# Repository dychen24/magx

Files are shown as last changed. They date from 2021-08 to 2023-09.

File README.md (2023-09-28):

# About

This directory contains codes and PCB files for MagX, as described in :

>  [_MagX: Wearable, Untethered Hands Tracking with Passive Magnets_]
>  Dongyao Chen, Mingke Wang, Chenxi He, Qing Luo,
>  Yasha Iravantchi, Alanson Sample, Kang G. Shin and Xinbing Wang.
>  In Proceedings of the ACM MobiCom 2021.

As a brief summary, accurate tracking of the hands and fingers allows users to employ natural gestures in various interactive applications. Hand tracking also supports health applications, such as monitoring face-touching, a common vector for infectious disease. However, for both types of applications, the utility of hand tracking is often limited by the impracticality of bulky tethered systems (e.g., instrumented gloves) or inherent limitations (e.g., Line of Sight or privacy concerns with vision-based systems).

We present MagX, a fully untethered on-body hand tracking system utilizing passive magnets and a novel magnetic sensing platform.  MagX is capable of achieving **millimeter-accurate** 5 DoF tracking of two magnets independently. For example, at 11 cm distance, a 6cm*6cm sensing array can achieve positional and orientational errors of 0.76 cm and 0.11 rad. At 21 cm distance, the tracking errors are 2.65 cm and 0.41 rad. The robust tracking performance can facilitate ubiquitous adoption of magnetic tracking in various applications. Furthermore, MagX can perform all compute locally and only requires ~0.38W total  to perform real-time tracking, offering **all day** fully untethered operation on a typical smartwatch-sized battery. 

plot

# License

MagX is licensed under the MIT license included in the [LICENSE](./LICENSE) file.

# Setup

To use MagX, you'll need the following tools and hardwares:
  * [MagX sensing array](#magx-sensing-array-manufacturing)
  * [Arduino IDE](#arduino-ide-setup)
  * [Anaconda](#python-environment-setup)
  * Homebrew for macOS

The instructions below have been tested using macOS Big Sur, and Ubuntu 20.04. 

## MagX sensing array manufacturing
To learn more about the manufacturing of the MagX sensing array, please see the related [README](./pcb/README.md) file in `/pcb`.

## Arduino IDE setup
1. Download and install [Arduino IDE](https://www.arduino.cc/en/software)
2. Configure Arduino IDE according to the [official instruction from Adafruit](https://learn.adafruit.com/bluefruit-nrf52-feather-learning-guide/arduino-bsp-setup)
3. install the Adafruit MLX90393 Library for Arduino using the Library Manager in the Arduino IDE:
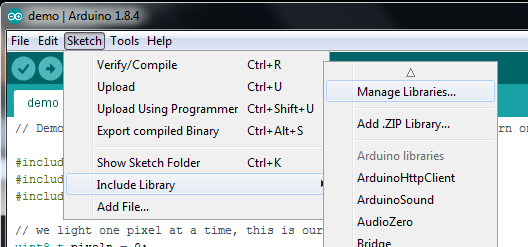
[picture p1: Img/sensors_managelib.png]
    

    Click the Manage Libraries ... menu item, search for Adafruit MLX90393, and select the Adafruit MLX90393 library:
    plot
4. (Optional) Replace `Adafruit_MLX90393.cpp` and `Adafruit_MLX90393.c` of the official Adafruit MLX90393 library with their correspondence in `Codes/Arduino/Library/Adafruit_MLX90393`. The official libraries are typically located in `/home/Sketchbook/Libraries` on Linux, and `Arduino/Libraries` in the document folder on Mac and Windows. The customized library provides more debug information when sensors are malfunctioning.

## Python environment setup
1. Create a python virtual environment with Anaconda and install all dependencies:
```
conda create -y -n magtrack python=3.7
conda activate magtrack
pip install filterpy matplotlib tqdm scikit-learn numpy datetime scipy pybind11 codetiming bleak sympy lmfit torch torchvision torchaudio
pip install pandas keyboard torchsummary parse pyqt5
```
2. Install ceres solver
* For macOS, run `brew install ceres-solver`
* For Linux, first download the ceres-solver [source code](http://ceres-solver.org/installation.html). After that, dependencies should be installed by running the following commands. 
    ```
    # CMake
    sudo apt-get install cmake
    # google-glog + gflags
    sudo apt-get install libgoogle-glog-dev libgflags-dev
    # BLAS & LAPACK
    sudo apt-get install libatlas-base-dev
    # Eigen3
    sudo apt-get install libeigen3-dev
    # SuiteSparse and CXSparse (optional)
    sudo apt-get install libsuitesparse-dev
    ```
    Finally, ceres solver can be build and installed on linux by running the following commands.
    ```
    tar zxf ceres-solver-2.0.0.tar.gz
    mkdir ceres-bin
    cd ceres-bin
    cmake ../ceres-solver-2.0.0
    make -j3
    make install
    ```
3. Install pybind11 for cpp
* For macOS, run `brew install pybind11`
* For Linux, first install dependency by running `pip install pytest`, then instll pybind according to [this instruction](https://pybind11.readthedocs.io/en/stable/basics.html).
4. Install customized cpp solver
    ```
    cd Codes/cpp_solver 
    pip install ./

# Run a quick demo
1. Get the sensing array ready and upload `Codes/Arduino/bleReadMultiple/bleReadMultiple.ino` to the sensing array
2. Run `Codes/read_raw_ble/find_device.py` to find the address of the Adafruit chip you are using. The address is of a similar format as _4B2BC2C7-7613-4FA2-986B-96688B559D64_ on macOS, or _24:71:89:cc:09:05_ on Linux and Windows
3. Before running `Codes/read_raw_ble/read_sensor.py`, replace the BLE address on line 66 with the address found in step 2. Also, change the output file name on line 31.
4. Run `Codes/read_raw_ble/read_sensor.py` to collect calibration data for the sensors. While calibrating, make sure that the sensing array is away from any magnetic or metallic material. Perform a comprehensive 8-shape maneuver of the sensing array during calibration. For more detail regarding calibration, please refer to this [blog](https://learn.adafruit.com/adafruit-sensorlab-magnetometer-calibration). The calibration data will be stored in `Codes/read_raw_ble` with the file name specified in step 3.
5. Before running `Codes/optimization/real_time_pos.py`, replace the BLE address on line 53 with the address found in step 2. Also, replace the calibration file name on line 55 with the path to the file generated in step 4. 
7. Run `Codes/optimization/real_time_pos.py`. 
    * By default, the code tracks 1 magnet. To track 2 magnets, change line 318 to `asyncio.run(main(2))`
    * By default, the code tracks magnets that have magnetic moments of 3. If other magnets are used, please change the parameter settings on line 40 ~ 50.
    * By default, the code assumes that the 9.8cm\*9.8cm (aka the "large") sensor array is used. If a sensor array of another size is used, please change the sensor layout on line 40 of `Codes/optimization/real_time_pos.py`. The code ships with 3 sensor layouts, the 9.8cm\*9.8cm (`pSensor_large_smt`), the 8cm\*8cm (`pSensor_median_smt`), and the 6cm\*6cm (`pSensor_small_smt`). 

# Code Layout

See the [Codes](./Codes/codes.md) file for more details on the various files in the repository.

# Version History
- v0.1:  Initial code release

# Citing MagX
If you use MagX in your research or wish to refer to the baseline results, please use the following BibTeX entry.

```BibTeX
@inproceedings{MagX2021,
  author    = {Chen, Dongyao and Wang, Mingke and He, Chenxi and Luo, Qing and Iravantchi, Yasha and Sample, Alanson and Shin, Kang G. and Wang, Xinbing},
  title     = {MagX: Wearable, Untethered Hands Tracking with Passive Magnets},
  year      = {2021},
  isbn      = {9781450383424},
  publisher = {Association for Computing Machinery},
  address   = {New York, NY, USA},
  url       = {https://doi.org/10.1145/3447993.3483260},
  doi       = {10.1145/3447993.3483260},
  booktitle = {Proceedings of the 27th Annual International Conference on Mobile Computing and Networking},
  pages     = {269–282},
  numpages  = {14},
  keywords  = {untethered, hand tracking, magnetic sensing},
  location  = {New Orleans, Louisiana},
  series    = {MobiCom '21}
}
```

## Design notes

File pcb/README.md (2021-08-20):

# PCB Design

## Folder Description
"6cmX6cm_layout" is a 6cm X 6cm sensing array, and "9.8cmX9.8cm_layout" is a 9.8cm X 9.8cm sensing array. Both of them are composed of two printed circuit board, top board and bottom board.

"bom" refers to bill of materials, i.e., the components needed to build a sensing array.

## PCB Design Tool and Library
We utilize Altium Designer (version 20.0.13) to design PCB boards. The component library of capacitive and resistance adopts the standard library. The footprint of magnetic field sensor, MLX90393, can see https://www.snapeda.com/parts/MLX90393SLW-ABA-011-RE/Melexis%20Technologies/view-part/551380/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.

## Assembly
We use 9 separate pin headers to join the two boards together. A common 3-pin linear regulator is used to stabilize the output voltage, which is set to 3.3v. A 16-pin female header and a 12-pin female header are welded to the bottom board to connect the Bluefruit nRF52 Feather.

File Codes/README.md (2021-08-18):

# All codes for MagX

## Arduino
1. batteryTest: read battery voltage and level of an Adafruit Feather
2. bleReadMultiple: read readings from 8 magnetometers and send them via bluetooth
3. localReadMultiple: read readings from 8 magnetometers and print them in serial port
4. Library: modified library for Adafruit_MLX90393

## leapmotion
Code for gathering groundtruth using a Leap Motion Controller. The ground truth is stored in a csv file. Leap Motion 2.7 python SDK must be first installed

## read_raw_ble
Read measurements from an Adafruit Feather sent by bluetooth. Before reading the measurement using read_sensor.py, use find_device.py to find the address of the device, and change the address in read_sensor.py accordingly

## cpp_solver
C++ wrapped solver of the LM algorithm.

## optimization
All codes for finding the optimal layout and tracking magnets. For more detail please refer to the readme file inside the folder.

## requirements.txt
All python libraries used

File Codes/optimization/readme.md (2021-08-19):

# The layout of the folder
- Visulization.py: used to track the magnet, visulize the result, and compare the result to the ground truth offline. The ground truth and the data should be stored as CSV (likely gathered by codes in `../leapmotion` and `../read_raw_ble`).
- real_time_pos.py: used to show the tracking result in real-time.
    - real_time_pos_belly.py: used for endocapsule tracking demo.
    - real_time_pos_car.py: used for driver hand monitoring demo.
    - real_time_pos_face.py: used for face touching demo.
    - real_time_pos_hand.py: used for hand tracking demo.
- simulation.py: generate simulated data and use it to validate the performance of the sensor layout.
- find_best_Loc.py: use PSO to find the best layout of the sensor array given the physical constraint.

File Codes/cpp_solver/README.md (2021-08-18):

# Readme
This folder stores the cpp implementation of the LM algorithm. 
The source file locates in  *./src*

This library consist three functions:
- solve_1mag
- solve_2mag
- CalB

## Usage
### solve_1mag
- input:
  - readings: the sensor readings at time $t$
  - pSensor: the location of each sensor
  - init_param: the initialization parameters. It's a array of size 9. The meaning of each parameter goes in the following order: 
  $G_x, G_y , G_z, log(m), x, y, z, \theta, \phi$.**Noted that logrithm should be applied to magnet moment $m$**

- output:
  - result: It's a array of size 9, just like _init_param_ . This set of parameter fit the sensor reading the best.

### solve_2mag
- input:
  - readings: the sensor readings at time $t$
  - pSensor: the location of each sensor
  - init_param: the initialization parameters. It's a array of size 9. The meaning of each parameter goes in the following order: 
  $G_x, G_y , G_z, log(m), x_0, y_0, z_0, \theta_0, \phi_0, x_1, y_1, z_1, \theta_1, \phi_1$

- output:
  - result: It's a array of size 9, just like _init_param_ . This set of parameter fit the sensor reading the best. **Noted that in the function both magnet has the same magnet moment $m$**.

### CalB
- input:
  - pSensor: the location of each sensor
  - init_param: the initialization parameters. It's a array of size 9. The meaning of each parameter goes in the following order: 
  $G_x, G_y , G_z, m, x, y, z, \theta, \phi$

- output:
  - result: The result is the simulated sensor reading given the magnet position and the sensor position.

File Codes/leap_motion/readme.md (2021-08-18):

# Leap Motion Setup Procedure

1. Download and install [Leap Motion SDK](https://developer.leapmotion.com/sdk-leap-motion-controller). We used Version 2.3.1 on macOS.
2. Put `LeapPython.so`, `libLeap.dylib` and `Leap.py` in `LeapSDK/lib` into this folder.
3. Plug the leap motion controller into your computer and run the Leap Motion Diagnostic Visualizer to check if the device is working properly.
4. Turn on the tool tracking mode and turn off the hand tracking mode of Leap Motion. On macOS, the settings are under `Tracking` of `Leap Motion Control Panel`.
5. Run `ground_truth.py` with Python 2.7. Change the output file name at the beginning of the file in advance. 
6. For more information regarding Leap Motion, please visit [this website](https://developer.leapmotion.com/desktop-leap-motion-controller/). During the first run of the code, you might encounter error `Fatal Python error: PyThreadState_Get: no current thread`. Please refer to this [page](https://stackoverflow.com/questions/42401156/leap-motion-error-fatal-python-error-pythreadstate-get-no-current-thread-abor) for a fix

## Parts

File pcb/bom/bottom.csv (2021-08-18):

Comment | Description | Designator | Footprint | LibRef | Pins | Quantity
0.1uF | capacitance | C7_2,C7,C11_2,C11,C15_2,C15,C16_2,C16 | CAP_0603 | CAP | 2 | 8
10k | resistance | R1,R2 | RES_0603 | RES | 2 | 2
MLX90393 | sensor | MS7,MS11,MS15,MS16 | MLX90393 | MLX90393SLW ABA 011 RE | 17 | 4

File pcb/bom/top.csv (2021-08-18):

Comment | Description | Designator | Footprint | LibRef | Pins | Quantity
0.1uF | capacitance | C30_2,CSD,CSD_2,CSC,CSC_2,C30,C27,C27_2 | CAP_0603 | CAP | 2 | 8
MLX90393 | sensor | MSSD,MSSC,MS30,MS27 | MLX90393 | MLX90393SLW ABA 011 RE | 17 | 4

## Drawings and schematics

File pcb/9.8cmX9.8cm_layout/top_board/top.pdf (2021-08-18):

SC27

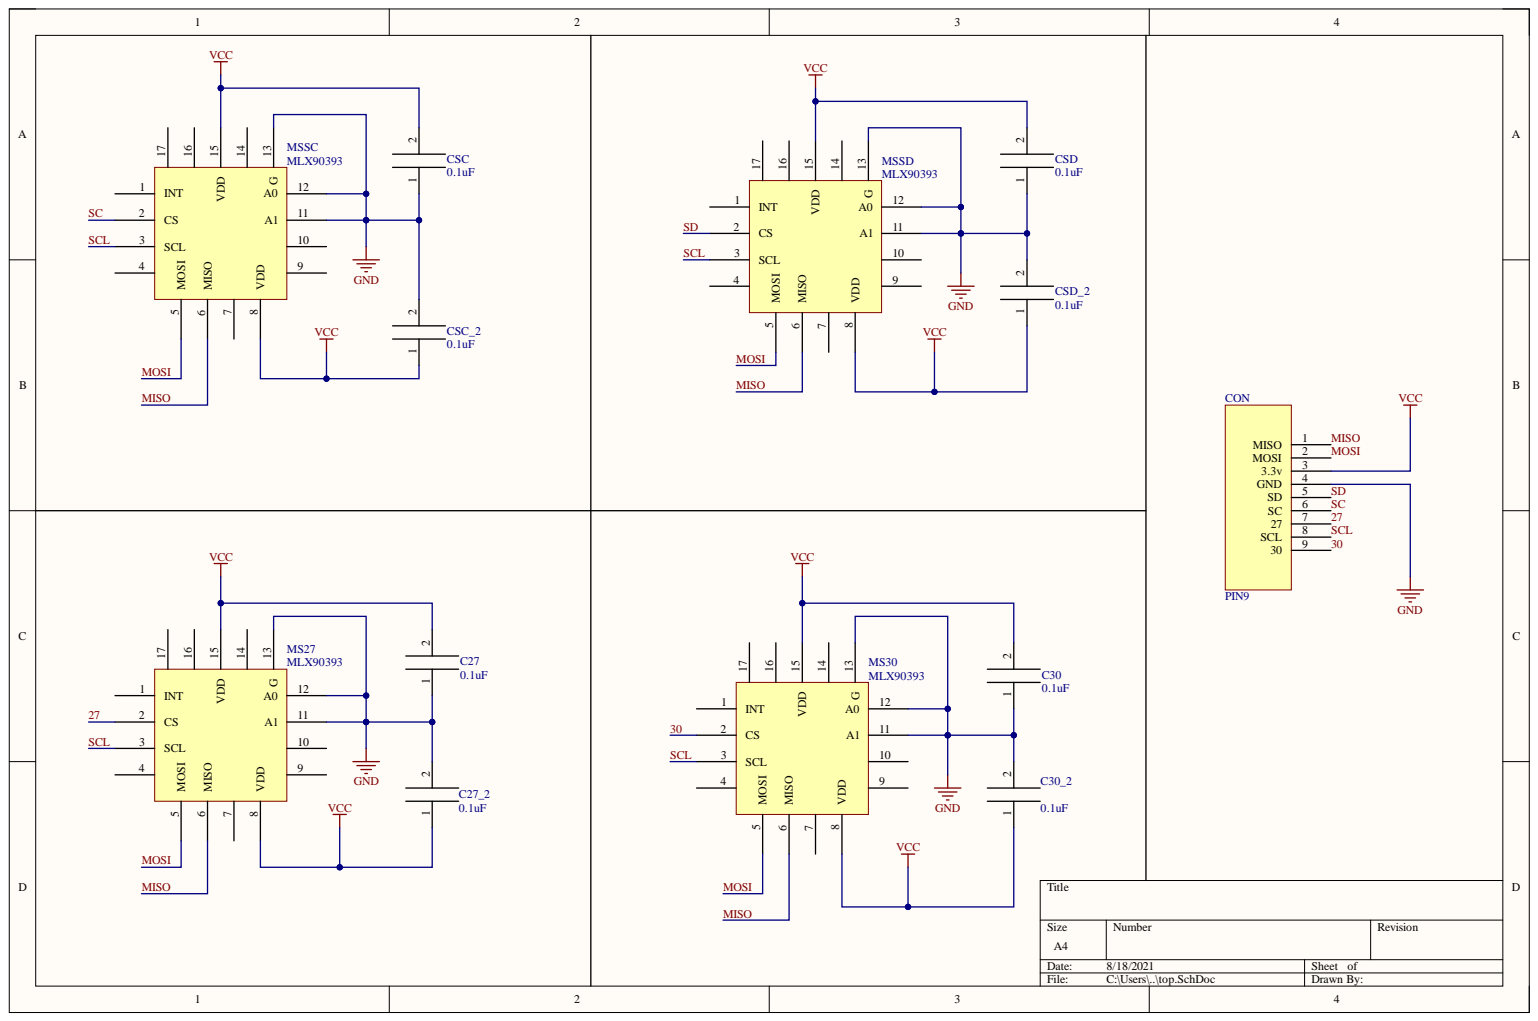
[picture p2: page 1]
Size; mber; Rev; Date:; Sheet o; sers; p.Sch; Draw; CSC 0.1uF; CSD 0.1uF; CSC_; CSD; MISO; MOSI; SCL; VCC; VCC GND; MOSI 5; MISO 6; VDD 8; VDD 15; MSSC ML; MSSD ML

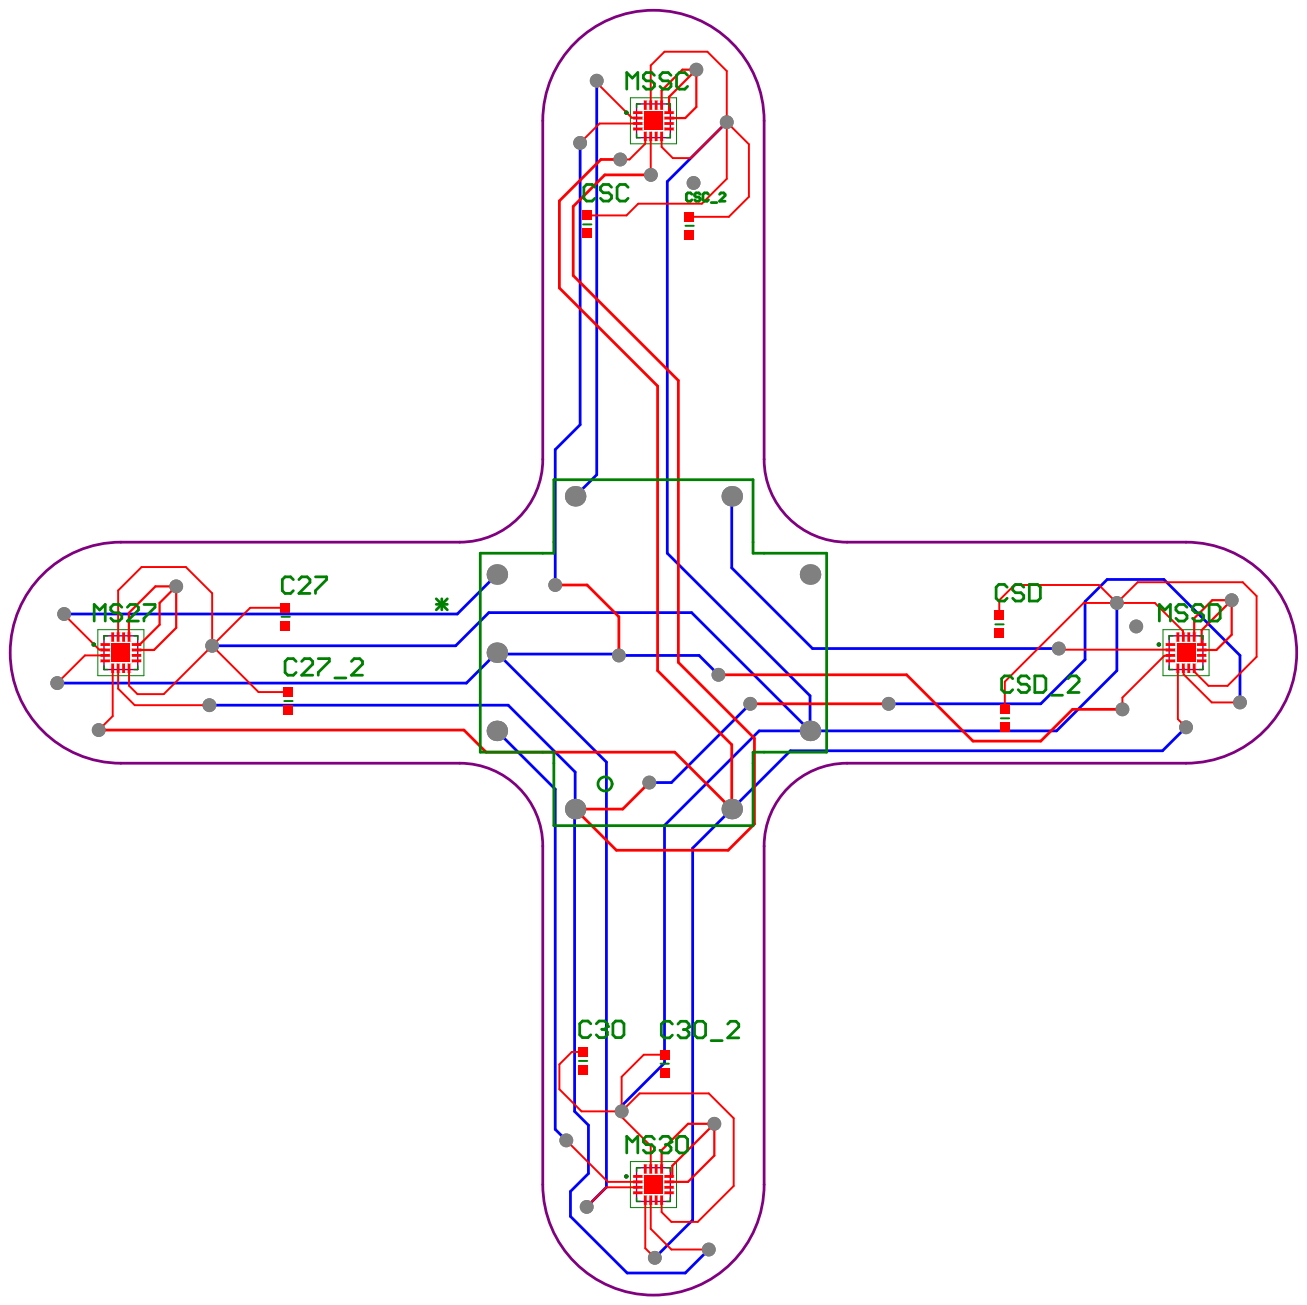
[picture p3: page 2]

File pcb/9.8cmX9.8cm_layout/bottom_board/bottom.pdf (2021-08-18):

4 | SCK 23 | A5 22 | A4 21 | A3 20 | A2 19 | A1 18 | A0 17 | GND 16 | 3.3v 15 | 3.3v 14 | RESE
2 SCL | 11 27 | 10 30 | 9 31 | 8 11 | 7 7 | 6 15 | 5 16 | 4 USB | 3 EN | 2

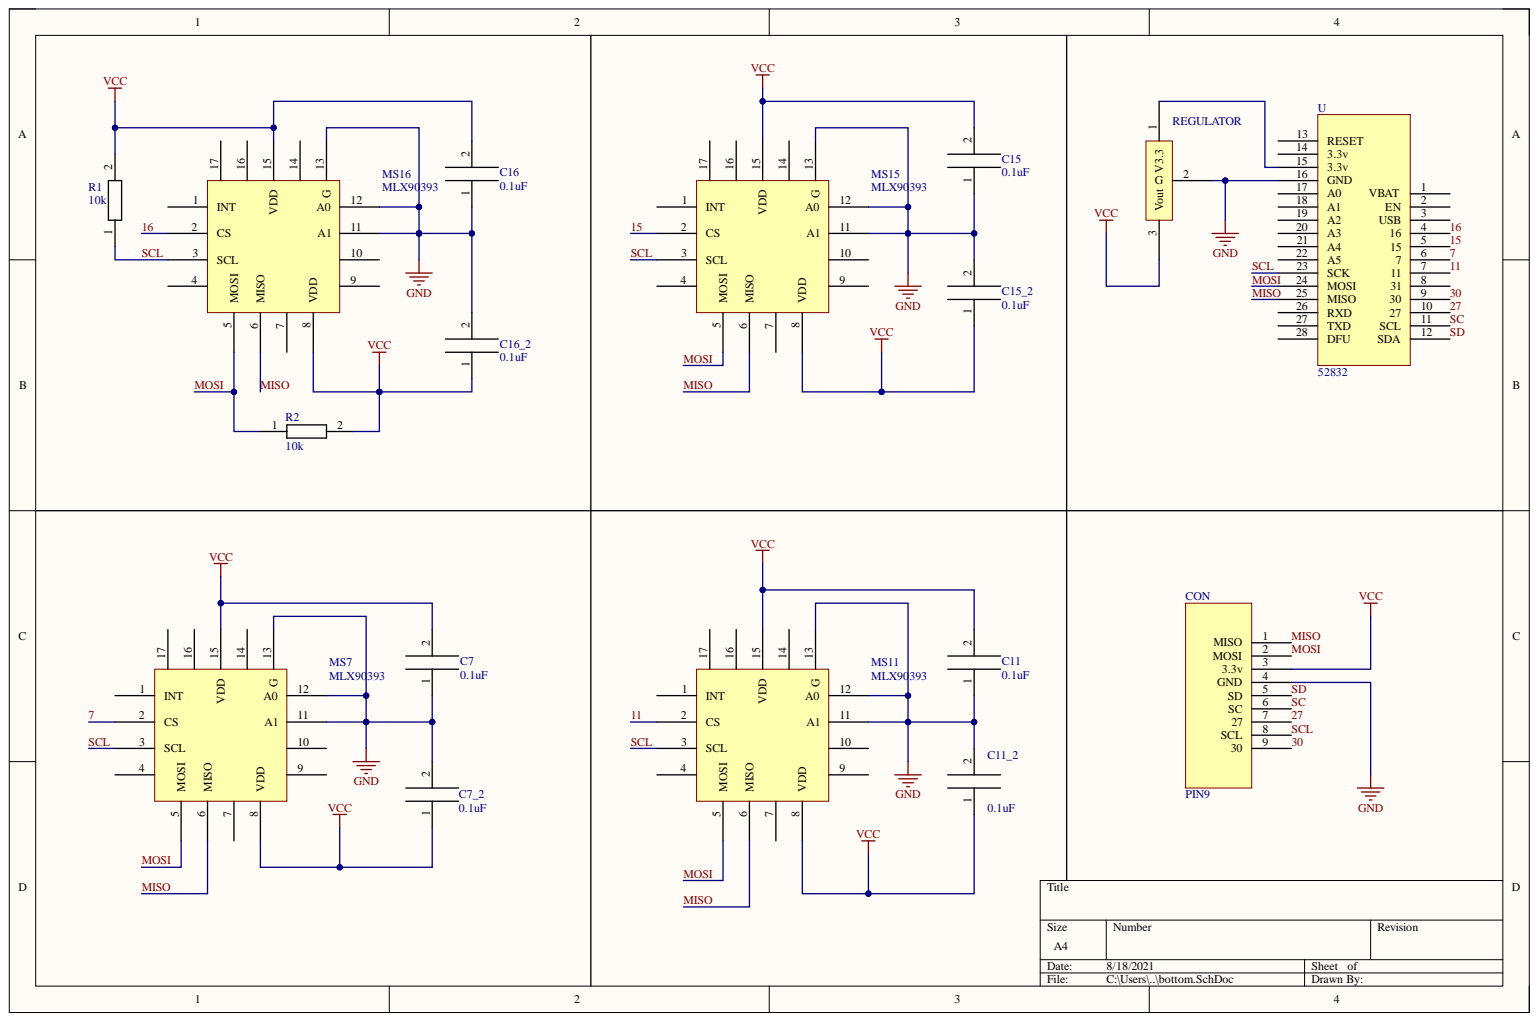
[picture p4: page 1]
Size; mber; Rev; Date:; Sheet o; sers; m.Sch; Draw; V3.3 1 Vout 3 G; DFU; MISO; MOSI; VBAT; SCL; VCC; R1 10kVCC; VCC GND; MOSI 5; MISO 6; VDD 8; VDD 15

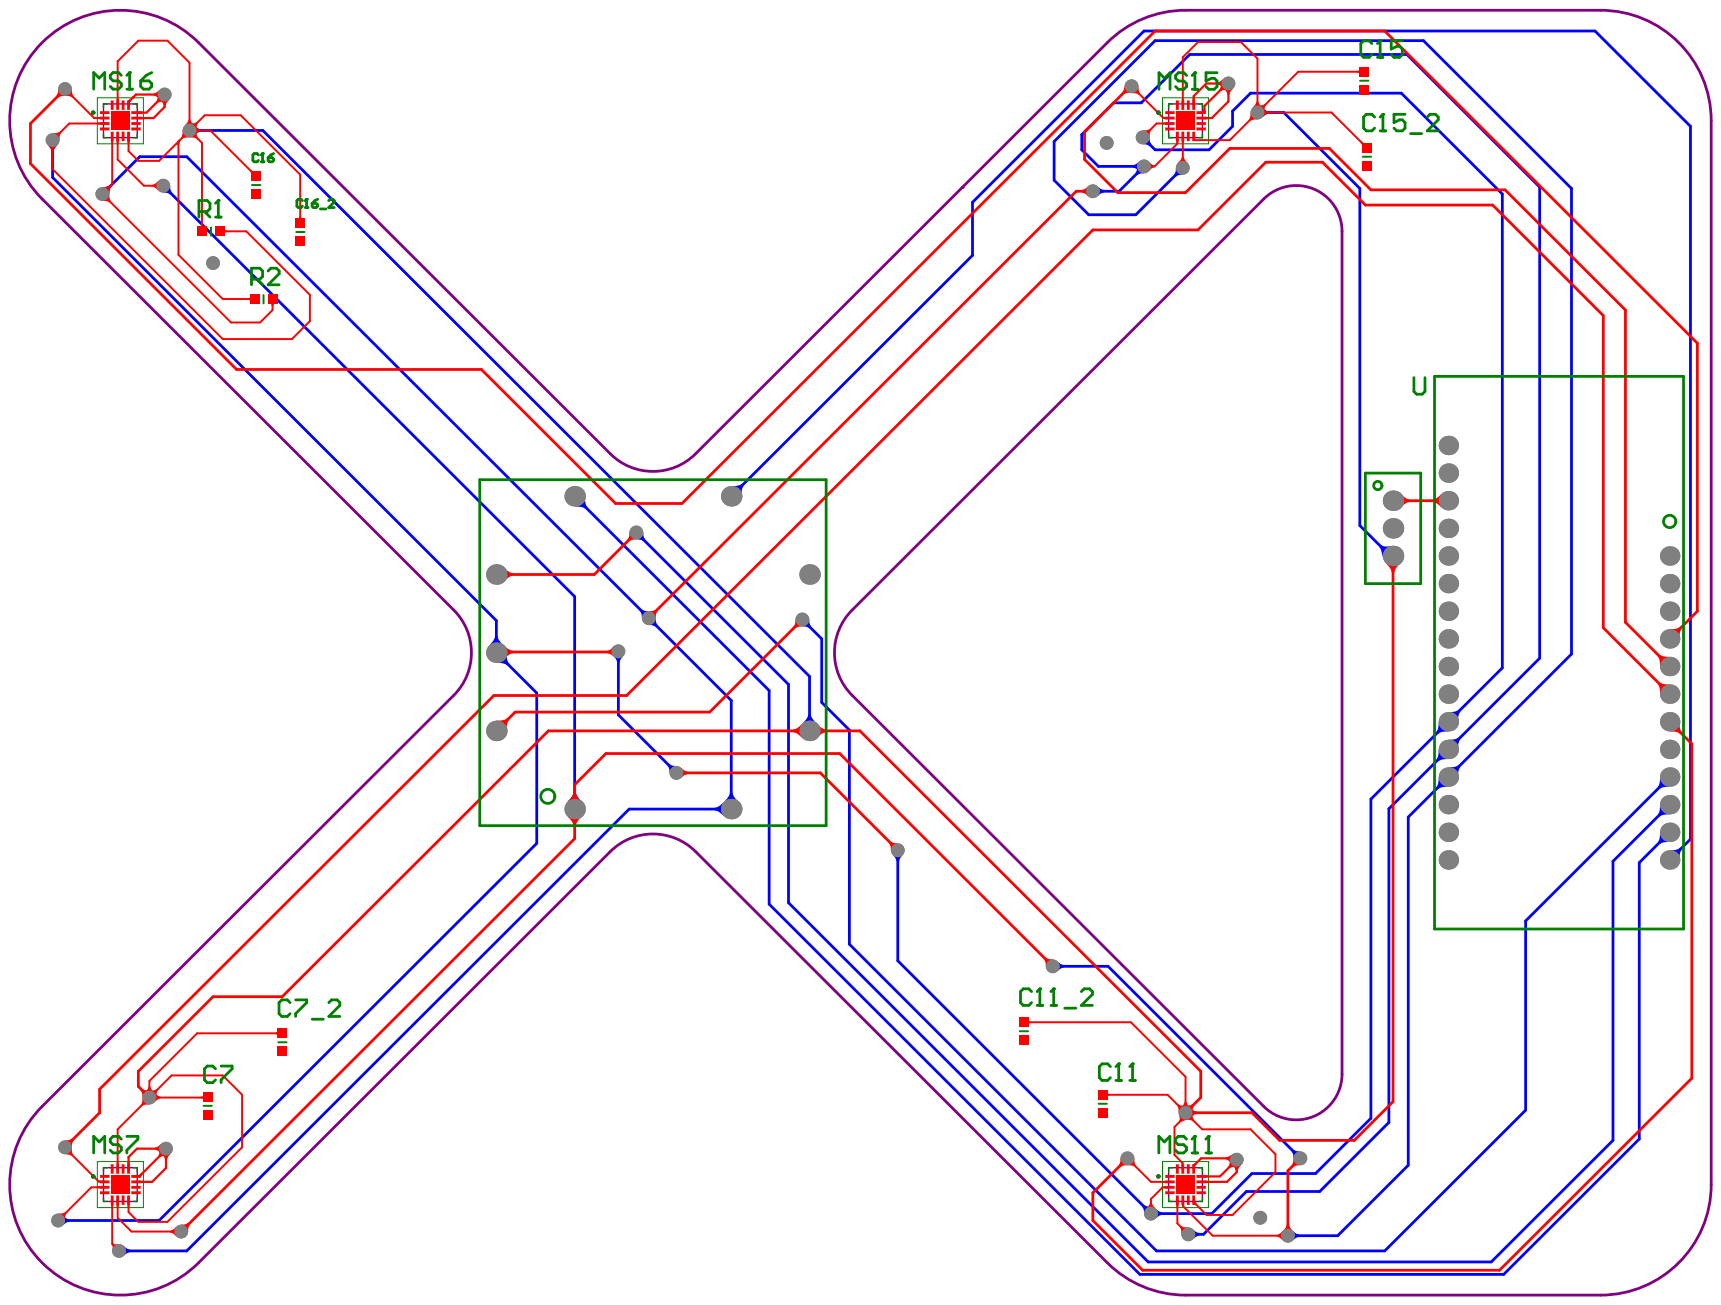
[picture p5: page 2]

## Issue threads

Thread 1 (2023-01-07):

issue with compiling with Adafruit_MLX90393.cpp

Myzhencai, 2023-01-07:
Hi ,@dychen24, thanks for sharing this awsome work:-)
As you can see, we build the PCB board and we want to make it work ,when we fllowed the instruction of the web:
https://learn.adafruit.com/bluefruit-nrf52-feather-learning-guide/arduino-bsp-setup
and we replaced the liabary of Adafruit_MLX90393(version2.0.0) with your Codes it seems when we compiled with this staff ,it come out with the fllowing errors : can you help with us :-)  ,hava a nice day :-)

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

Arduino: 1.8.19 (Linux), Board: "Adafruit Feather nRF52832, S132 6.1.1, Level 0 (Release), Serial"
/home/gaofei/Arduino/libraries/Adafruit_MLX90393/Adafruit_MLX90393.cpp: In member function 'bool Adafruit_MLX90393::writeRegister(uint8_t, uint16_t)':
/home/gaofei/Arduino/libraries/Adafruit_MLX90393/Adafruit_MLX90393.cpp:392:25: warning: narrowing conversion of '(((int)data) >> 8)' from 'int' to 'uint8_t' {aka 'unsigned char'} [-Wnarrowing]
  392 |                    data >> 8,   // high byte
      |                    ~~~~~^~~~
/home/gaofei/Arduino/libraries/Adafruit_MLX90393/Adafruit_MLX90393.cpp:393:25: warning: narrowing conversion of '(int)(((short unsigned int)((int)data)) & 255)' from 'int' to 'uint8_t' {aka 'unsigned char'} [-Wnarrowing]
  393 |                    data & 0xFF, // low byte
      |                    ~~~~~^~~~~~
/home/gaofei/Arduino/libraries/Adafruit_MLX90393/Adafruit_MLX90393.cpp:394:24: warning: narrowing conversion of '(((int)reg) << 2)' from 'int' to 'uint8_t' {aka 'unsigned char'} [-Wnarrowing]
  394 |                    reg << 2};   // the register itself, shift up by 2 bits!
      |                    ~~~~^~~~
/home/gaofei/Arduino/libraries/Adafruit_MLX90393/Adafruit_MLX90393.cpp: In member function 'bool Adafruit_MLX90393::readRegister(uint8_t, uint16_t*)':
/home/gaofei/Arduino/libraries/Adafruit_MLX90393/Adafruit_MLX90393.cpp:402:24: warning: narrowing conversion of '(((int)reg) << 2)' from 'int' to 'uint8_t' {aka 'unsigned char'} [-Wnarrowing]
  402 |                    reg << 2}; // the register itself, shift up by 2 bits!
      |                    ~~~~^~~~
/home/gaofei/Arduino/libraries/Adafruit_MLX90393/Adafruit_MLX90393.cpp: In member function 'mlx90393_resolution Adafruit_MLX90393::getResolution(mlx90393_axis)':
/home/gaofei/Arduino/libraries/Adafruit_MLX90393/Adafruit_MLX90393.cpp:235:1: error: control reaches end of non-void function [-Werror=return-type]
  235 | }
      | ^
cc1plus: some warnings being treated as errors
exit status 1
Error compiling for board Adafruit Feather nRF52832.

This report would have more information with
"Show verbose output during compilation"
option enabled in File -> Preferences.

Myzhencai, 2023-01-07:
by the way this is the pcb board we did as per the opensource file
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

Closed 2023-01-08.

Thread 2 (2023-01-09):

Calibrate_Data returns nan ?

Myzhencai, 2023-01-09:

Myzhencai, 2023-01-09:
Hi dychen,thanks for sharing . As you can see ,we have just make it with the instruction of your readme ,and the PCB works fine ,we just collect the data for calibration but wen we run the code :real_time_pos.py
we got the error like this :
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

and this is the collecte data of our PCB :
[file_name.csv](https://github.com/dychen24/magx/files/10371404/file_name.csv)

can you help with us for solving this issue ? is there any thing come with numpy or panda version make this happen? thanks for help:-) have a nice day:-0

Myzhencai, 2023-01-09:
By the way  this is the result of running real_time_pos.py ：

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

E0109 17:16:21.871924 85589 trust_region_minimizer.cc:71] Terminating: Residual and Jacobian evaluation failed.
Position: -2.00, 2.00, 11.00, dis=11.36
W0109 17:16:21.917574 89658 residual_block.cc:129]

Error in evaluating the ResidualBlock.

There are two possible reasons. Either the CostFunction did not evaluate and fill all
residual and jacobians that were requested or there was a non-finite value (nan/infinite)
generated during the or jacobian computation.

Residual Block size: 8 parameter blocks x 3 residuals

For each parameter block, the value of the parameters are printed in the first column
and the value of the jacobian under the corresponding residual. If a ParameterBlock was
held constant then the corresponding jacobian is printed as 'Not Computed'. If an entry
of the Jacobian/residual array was requested but was not written to by user code, it is
indicated by 'Uninitialized'. This is an error. Residuals or Jacobian values evaluating
to Inf or NaN is also an error.

Residuals:              inf          inf      219.454

Parameter Block 0, size: 1

       -0.02 |      2096.42      656.464     -2226.92

Parameter Block 1, size: 1

        0.02 |      656.464      2096.42      2226.92

Parameter Block 2, size: 1

        0.11 |     -2226.92      2226.92     -4192.84

Parameter Block 3, size: 1

           0 |     -109.786     -18.3308      79.8336

Parameter Block 4, size: 1

           0 |            0            0            0

Parameter Block 5, size: 1

 2.82843e-05 |        1e+06            0            0

Parameter Block 6, size: 1

 2.82843e-05 |            0        1e+06            0

Parameter Block 7, size: 1

           0 |            0            0        1e+06

Myzhencai, 2023-01-09:
By the way  this is the result of running real_time_pos.py ：

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

E0109 17:16:21.871924 85589 trust_region_minimizer.cc:71] Terminating: Residual and Jacobian evaluation failed.
Position: -2.00, 2.00, 11.00, dis=11.36
W0109 17:16:21.917574 89658 residual_block.cc:129]

Error in evaluating the ResidualBlock.

There are two possible reasons. Either the CostFunction did not evaluate and fill all
residual and jacobians that were requested or there was a non-finite value (nan/infinite)
generated during the or jacobian computation.

Residual Block size: 8 parameter blocks x 3 residuals

For each parameter block, the value of the parameters are printed in the first column
and the value of the jacobian under the corresponding residual. If a ParameterBlock was
held constant then the corresponding jacobian is printed as 'Not Computed'. If an entry
of the Jacobian/residual array was requested but was not written to by user code, it is
indicated by 'Uninitialized'. This is an error. Residuals or Jacobian values evaluating
to Inf or NaN is also an error.

Residuals:              inf          inf      219.454

Parameter Block 0, size: 1

       -0.02 |      2096.42      656.464     -2226.92

Parameter Block 1, size: 1

        0.02 |      656.464      2096.42      2226.92

Parameter Block 2, size: 1

        0.11 |     -2226.92      2226.92     -4192.84

Parameter Block 3, size: 1

           0 |     -109.786     -18.3308      79.8336

Parameter Block 4, size: 1

           0 |            0            0            0

Parameter Block 5, size: 1

 2.82843e-05 |        1e+06            0            0

Parameter Block 6, size: 1

 2.82843e-05 |            0        1e+06            0

Parameter Block 7, size: 1

           0 |            0            0        1e+06

Wangmerlyn, 2023-12-23:
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
Based on the raw data returned from your sensor, there appears to be an issue with the raw data itself. The absolute values of the Z-axis readings are too large. When this occurs, it could be indicative of a malfunction in your sensor, or it might be caused by a sporadic issue. Please try resetting your sensor several times and then recalibrate it, ensuring that the readings are within the normal range of a few tens of microteslas before proceeding with subsequent operations. If you continue to get abnormal readings, it is possible that there is a problem with the sensor.

Closed 2023-12-25.

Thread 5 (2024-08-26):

When attempting to reproduce the MagX Demo, although the environment setup and sensor data collection were successfully completed, the calibration results did not display correctly, and the positioning program failed to accurately locate the magnetic ball.

developdy, 2024-08-26:
Dear Professor Chen,

I'm very interested in your MagX Demo and believe it has significant practical value. We're attempting to replicate the work from the related paper. We've successfully completed the environment setup, device search, and sensor data collection as per the Readme. These steps went smoothly, but we're encountering issues during the calibration process:

1.No Display After Calibration:
After calibrating the magnetometer as described in the paper, the results are unsatisfactory. The left plot shows the scatter plot of the magnetometer measurements before and after calibration from the paper, while the right plot shows our results. We noticed significant deviations in both pre- and post-calibration results, and the post-calibration scatter plot doesn't display at all.
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
2.Visualization Issue in real_time_pos.py:
When executing real_time_pos.py, the visualization only shows eight sensors without locating the magnet ball's position.
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
We've successfully found the device using Codes/read_raw_ble/find_device.py and received data from eight sensors using Codes/read_raw_ble/read_sensor.py.
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

 The readings change as the magnet ball approaches the sensors. However, Codes/optimization/real_time_pos.py only displays the eight sensors and fails to locate the magnet ball.
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

Could you provide guidance or suggestions to help us resolve these issues?

Thank you for your assistance!

Duan Yu
PhD Student, Xidian University

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
developdy, 2024-09-06:
Issue: File Link Blocked by MediaFire
Dear Professor Chen,

I hope this message finds you well. Unfortunately, the following link has been flagged as a "Dangerous File" by MediaFire and is currently blocked: https://www.mediafire.com/file/zch0v8rj7200mbm/fix.zip/file. As a result, I am unable to access the file. Could you kindly resend the file using a different platform or method? Your assistance with this matter would be greatly appreciated.

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

Best regards,
Yu Duan
Xidian University

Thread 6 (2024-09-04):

Sensor Data Processing Results in NaN Values in Scale Matrix

developdy, 2024-09-04:
Dear Professor Chen,

Thank you for your prompt response to our previous issue. Your guidance helped us resolve it perfectly, and we are truly grateful for your support.

However, we have encountered a new challenge:

Problem Description:
While processing sensor data using read_sensor.py and saving it as a CSV file, some readings for the three axes are recorded as zero. This could potentially impact our results.
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
Additionally, during the execution of real_time_pos.py, which reads this CSV file to display trajectories, we observed that the scale matrix contains NaN values, leading to failures in magnetic sphere trajectory tracking. Below are the details:
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
Offset Matrix: Values appear normal.
Scale Matrix: Contains NaN values.
We attempted various sensor environments and orientations during CSV generation but could not prevent NaN values in the scale matrix. The occurrence of zero values is consistent across trials for specific sensors, while others remain unaffected.

Certainly. Here are some attempts we made:
1.Tried different sensor environments and orientations.
2.Set NaN values to a fixed number (50.5) but observed a significant drop in 3D visualization accuracy.

Request for Guidance
Could you please advise on:
1.Specific considerations during CSV generation to prevent zero or NaN values?
2.Possible causes for the occurrence of these NaN values?
Thank you for your continued support and guidance.

Best regards,

Yu Duan
Xidian University

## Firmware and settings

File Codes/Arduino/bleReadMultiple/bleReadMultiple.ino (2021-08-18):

#include <bluefruit.h>
#include <Adafruit_LittleFS.h>
#include <InternalFileSystem.h>
#include "Adafruit_MLX90393.h"

#define num 8

Adafruit_MLX90393 sensor[num];
int CS[num] = {16,  15, 7, 11,26,25,27,30};

//int CS[num] = {16,  15, 7, 11,30,27};

// BLE Service
BLEDfu  bledfu;  // OTA DFU service
BLEDis  bledis;  // device information
BLEUart bleuart; // uart over ble
BLEBas  blebas;  // battery

float data_array[num*3+1];   // The array to hold the data

void setup()
{
  dwt_enable();         // For more accurate micros() on Feather
  Serial.begin(115200);
#if CFG_DEBUG
  // Blocking wait for connection when debug mode is enabled via IDE
  while ( !Serial ) yield();
#endif
  //********************BLE SETUP*******************//
  Serial.println("Bluefruit52 BLEUART Example");
  Serial.println("---------------------------\n");

  // Setup the BLE LED to be enabled on CONNECT
  // Note: This is actually the default behavior, but provided
  // here in case you want to control this LED manually via PIN 19
  Bluefruit.autoConnLed(true);

  // Config the peripheral connection with maximum bandwidth 
  // more SRAM required by SoftDevice
  // Note: All config***() function must be called before begin()
  Bluefruit.configPrphBandwidth(BANDWIDTH_MAX);

  Bluefruit.begin();
  Bluefruit.setTxPower(4);    // Check bluefruit.h for supported values
  Bluefruit.setName("Bluefruit52");
  //Bluefruit.setName(getMcuUniqueID()); // useful testing with multiple central connections
  Bluefruit.Periph.setConnectCallback(connect_callback);
  Bluefruit.Periph.setDisconnectCallback(disconnect_callback);

  // To be consistent OTA DFU should be added first if it exists
  bledfu.begin();

  // Configure and Start Device Information Service
  bledis.setManufacturer("Adafruit Industries");
  bledis.setModel("Bluefruit Feather52");
  bledis.begin();

  // Configure and Start BLE Uart Service
  bleuart.begin();

  // Start BLE Battery Service
  blebas.begin();
  blebas.write(100);

  // Set up and start advertising
  startAdv();

  //*****************SENSOR SETUP*****************//
  pinMode(LED_BUILTIN, OUTPUT);     // Indicator of whether the sensors are all found
  digitalWrite(LED_BUILTIN, LOW);
  delayMicroseconds(2);
  for(int i = 0; i < num; ++i){
    sensor[i] = Adafruit_MLX90393();
    while (! sensor[i].begin_SPI(CS[i])) {
      Serial.print("No sensor ");
      Serial.print(i+1);
      Serial.println(" found ... check your wiring?");
      delayMicroseconds(500);
    } 
    Serial.print("Sensor ");
    Serial.print(i+1);
    Serial.println(" found!");
    while(!sensor[i].setOversampling(MLX90393_OSR_3)){
      Serial.print("Sensor ");
      Serial.print(i+1);
      Serial.println(" reset OSR!");
      delayMicroseconds(500);
    }
    delayMicroseconds(500);
    while(!sensor[i].setFilter(MLX90393_FILTER_5)){
      Serial.print("Sensor ");
      Serial.print(i+1);
      Serial.println(" reset filter!");
      delayMicroseconds(1000);
    }
  } 
  digitalWrite(LED_BUILTIN, HIGH);
  Serial.println("Found all MLX90393 sensors");
  
}

void startAdv(void)
{
  // Advertising packet
  Bluefruit.Advertising.addFlags(BLE_GAP_ADV_FLAGS_LE_ONLY_GENERAL_DISC_MODE);
  Bluefruit.Advertising.addTxPower();

  // Include bleuart 128-bit uuid
  Bluefruit.Advertising.addService(bleuart);

  // Secondary Scan Response packet (optional)
  // Since there is no room for 'Name' in Advertising packet
  Bluefruit.ScanResponse.addName();
  
  /* Start Advertising
   * - Enable auto advertising if disconnected
   * - Interval:  fast mode = 20 ms, slow mode = 152.5 ms
   * - Timeout for fast mode is 30 seconds
   * - Start(timeout) with timeout = 0 will advertise forever (until connected)
   * 
   * For recommended advertising interval
   * https://developer.apple.com/library/content/qa/qa1931/_index.html   
   */
  Bluefruit.Advertising.restartOnDisconnect(true);
  Bluefruit.Advertising.setInterval(32, 244);    // in unit of 0.625 ms
  Bluefruit.Advertising.setFastTimeout(30);      // number of seconds in fast mode
  Bluefruit.Advertising.start(0);                // 0 = Don't stop advertising after n seconds

}

void loop()
{ 
  int start_time = micros();
   //Serial.println("###################");
   for(int i = 0; i < num; ++i){
      sensor[i].startSingleMeasurement();
      //delayMicroseconds(50);
   }
   delayMicroseconds(mlx90393_tconv[5][3]*1000+500); 
   for(int i = 0; i < num; ++i){
      if(!sensor[i].readMeasurement(&data_array[3*i], &data_array[3*i+1], &data_array[3*i+2])){
        Serial.print("Sensor ");
        Serial.print(i+1);
        Serial.println(" no data read!");
        digitalWrite(LED_BUILTIN, LOW);
      }
      delayMicroseconds(700);
    }
    
    // delayMicroseconds(10000);
    
    // Measure battery voltage
    /*
    float measuredvbat = analogRead(A7);
    measuredvbat *= 2;    // we divided by 2, so multiply back
    measuredvbat *= 3.3;  // Multiply by 3.3V, our reference voltage
    measuredvbat /= 1024; // convert to voltage
    data_array[num*3] = measuredvbat;*/

    // Send to PC
    bleuart.write((byte*)(data_array), num*3*4+4);
    int elapsed_time = micros() - start_time;
    Serial.print(1000000 / elapsed_time);
    Serial.println(" Hz");
}


// callback invoked when central connects
void connect_callback(uint16_t conn_handle)
{
  // Get the reference to current connection
  BLEConnection* connection = Bluefruit.Connection(conn_handle);

  char central_name[32] = { 0 };
  connection->getPeerName(central_name, sizeof(central_name));

  Serial.print("Connected to ");
  Serial.println(central_name);
}

/**
 * Callback invoked when a connection is dropped
 * @param conn_handle connection where this event happens
 * @param reason is a BLE_HCI_STATUS_CODE which can be found in ble_hci.h
 */
void disconnect_callback(uint16_t conn_handle, uint8_t reason)
{
  (void) conn_handle;
  (void) reason;

  Serial.println();
  Serial.print("Disconnected, reason = 0x"); Serial.println(reason, HEX);
}

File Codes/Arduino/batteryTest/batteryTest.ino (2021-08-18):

#define VBAT_PIN          (A7)

// 3.0V ADC range and 12-bit ADC resolution = 3000mV/4096
#define VBAT_MV_PER_LSB   (0.73242188F)

// 2M + 0.806M voltage divider on VBAT = (2M / (0.806M + 2M))
#define VBAT_DIVIDER      (0.71275837F)

// Compensation factor for the VBAT divider
#define VBAT_DIVIDER_COMP (1.403F)

int vbat_raw;
uint8_t vbat_per;
float vbat_mv;

void setup(void) {
  Serial.begin(115200);
  analogReference(AR_INTERNAL_3_0);
  analogReadResolution(12);  // Can be 8, 10, 12 or 14
  delay(1);
}

void loop(void) {
  vbat_raw = analogRead(VBAT_PIN);
  vbat_per = mvToPercent(vbat_raw * VBAT_MV_PER_LSB);

  // FIXME: Using C-style cast.  Use static_cast<float>(...)
  // instead  [readability/casting] [4]
  // Remove [readability/casting] ignore from Makefile
  vbat_mv = (float)vbat_raw * VBAT_MV_PER_LSB * VBAT_DIVIDER_COMP;

  Serial.print("ADC = ");
  Serial.print(vbat_raw * VBAT_MV_PER_LSB);
  Serial.print(" mV (");
  Serial.print(vbat_raw);
  Serial.print(") ");
  Serial.print("LIPO = ");
  Serial.print(vbat_mv);
  Serial.print(" mV (");
  Serial.print(vbat_per);
  Serial.println("%)");

  delay(4000);
}

uint8_t mvToPercent(float mvolts) {
  uint8_t battery_level;

  if (mvolts >= 3000) {
    battery_level = 100;
  } else if (mvolts > 2900) {
    battery_level = 100 - ((3000 - mvolts) * 58) / 100;
  } else if (mvolts > 2740) {
    battery_level = 42 - ((2900 - mvolts) * 24) / 160;
  } else if (mvolts > 2440) {
    battery_level = 18 - ((2740 - mvolts) * 12) / 300;
  } else if (mvolts > 2100) {
    battery_level = 6 - ((2440 - mvolts) * 6) / 340;
  } else {
    battery_level = 0;
  }

  return battery_level;
}
